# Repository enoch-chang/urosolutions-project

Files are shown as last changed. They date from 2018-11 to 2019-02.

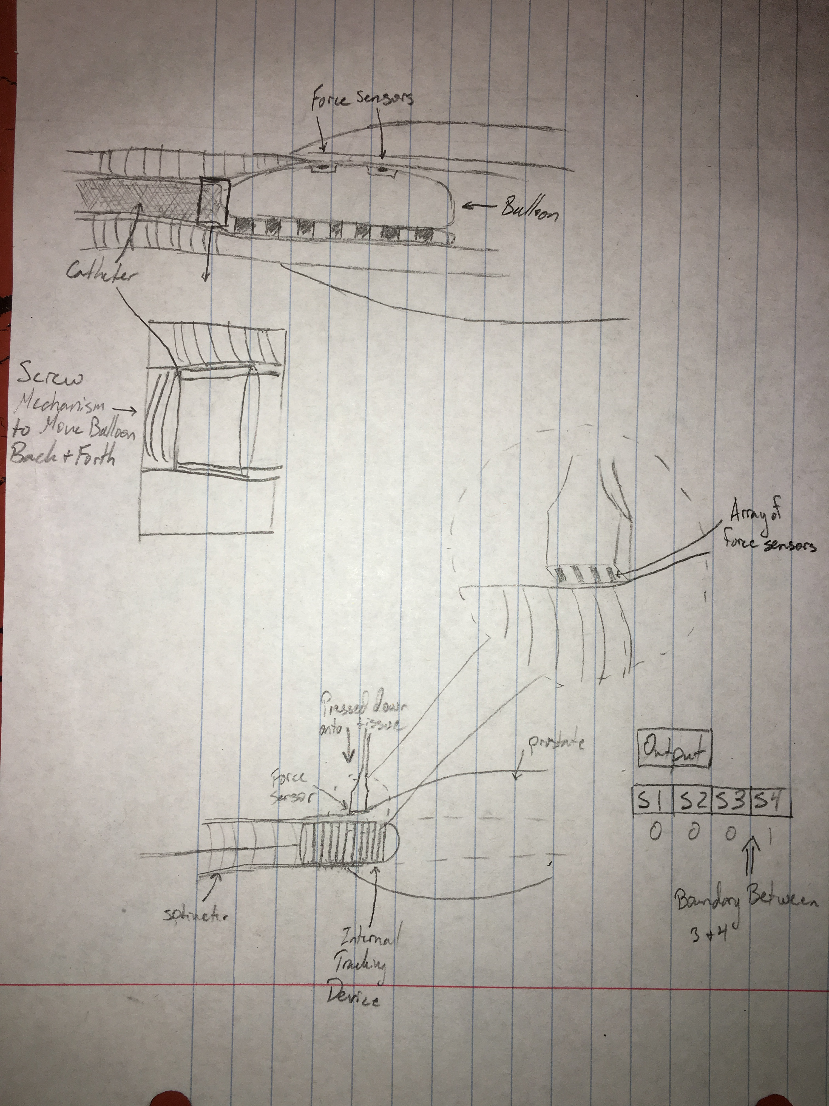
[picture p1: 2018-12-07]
Prototyping/Force_Sensing_Internal_External.JPG

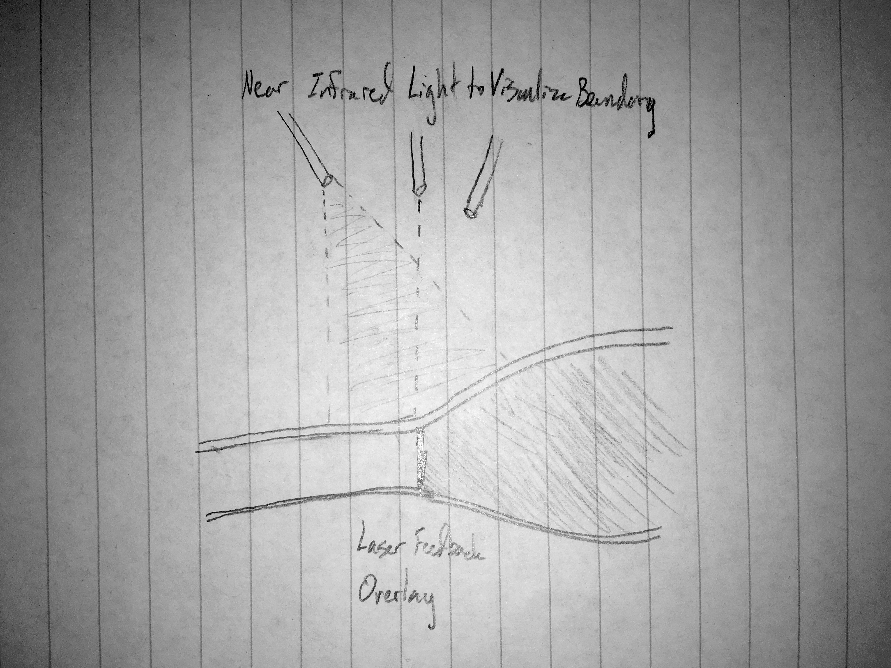
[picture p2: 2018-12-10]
Prototyping/Infrared_Sensing_Laser_Guidance.JPG

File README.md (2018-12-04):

# UroSolutions Project

This is the design repository for UroSolutions. Although the team collaborates on the documentation over Google Docs due to its real-time capabilities, all completed documentation is also uploaded onto the GitHub. 

The GitHub repository is organized into two main folders: Documentation and Prototyping. The Documentation contains files such as functional decomposition, the Design Foundation Document, background research and relevant Pugh matrices used to support design decisions. The Prototyping folder contains all material related to engineering aspects, from sketches, materials, CAD models, code and testing data for various iterations. Our Prototyping also includes relevant materials used in designing the testing models used to test our prototypes. Furthermore, the Milestones feature is used and updated regularly to facilitate achievement of objectives.

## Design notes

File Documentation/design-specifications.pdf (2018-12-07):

### Design Specifications

| | Spec #1 | Spec #2 | Spec #3 | Spec #4 | Spec #5
Priority | CUSTOMER NEEDS | Image Resolution | Measurement feedback time | Diameter of the device | Set-up and measurement time | Compatibility with surgical robotics
1 | The solution reduces recurrence of prostate cancer and severity of urinary incontinence | X
2 | The device clearly isolates and identifies the boundaries in imaging | X
3 | The solution does not present any additional sources of risk | | | X
4 | The solution must be simple to set-up and use | | X | | X | X
5 | The solution provides an indication for where to make surgical incisions | | X
6 | The device is compatible with laparoscopic surgical devices | | | | | X
| Competitive Value | - | - | 2.65 mm | - | -
| Marginal Value | - | - | 2.65 mm | - | -
| Ideal Value | 1 mm | 10 seconds | 2.6 mm | 10 minutes | Yes

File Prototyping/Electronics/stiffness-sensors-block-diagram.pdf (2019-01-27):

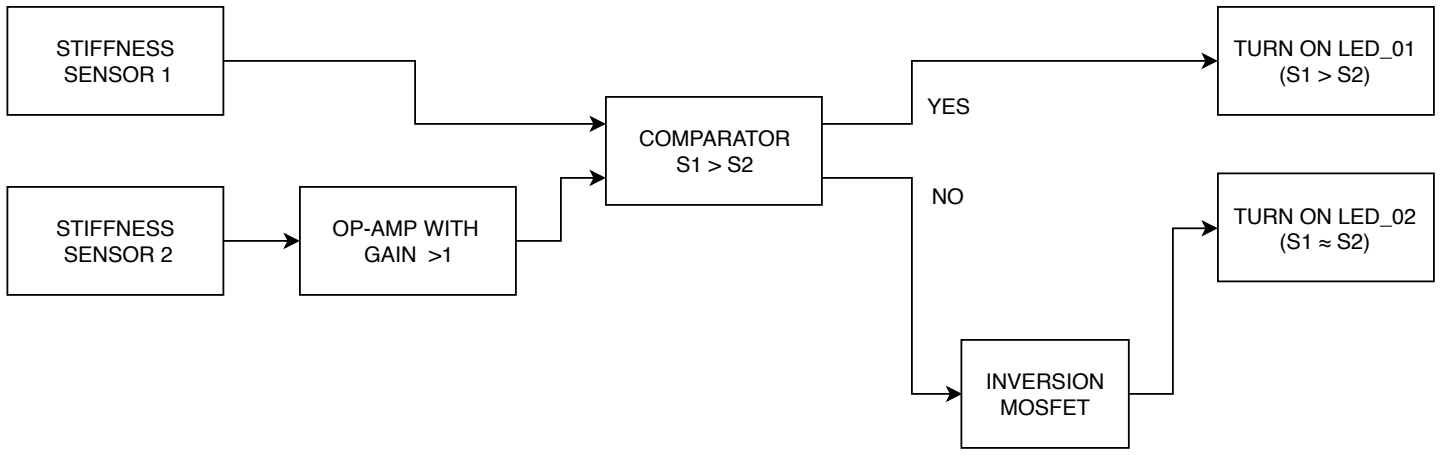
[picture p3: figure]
STIFFNESS SENSOR 1; STIFFNESS SENSOR 2; OP-AMP WITH GAIN >1; COMPARATOR S1 > S2; TURN ON LED_01 (S1 > S2); TURN ON LED_02 (S1 ≈ S2); YES; INVERSION MOSFET

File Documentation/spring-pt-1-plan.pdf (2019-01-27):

Spring Break Deliverable Plan: Functional Prototype

MVP

Our minimal viable product for the Spring break deadline will have the following characteristics and functionality:
- Detection of a stiffness difference between two media with stiffnesses representative of the sphincter and the prostate
- Balloon inflation mechanism is consistent and can attain stiffness readings
- Manual screw mechanism integrated with the balloon component and calibrated to attain the required imaging resolution
- Micro-controller software developed to be able to work through the full sequence of events (inflation, location detection/refinement, surgical tool positioning)
- Position of external sensor (for attachment onto the surgical tool) can be detected relative to the boundary that has been located

Tasks for after Spring Break (End of April Deadline)

Taking into account the initial vision and conception of the project scope, this is a list of features that will be implemented after Spring break for the final submission:
- Automation of the mechanical refinement process
- Improvement of the user input and display system to provide an intuitive user experience
- Adding additional sensors to increase ease of attaining an initial estimate of where the boundary is
- Optimize and reduce physical size of device (e.g. replacing Arduinos)

Schedule

Week | Stiffness | Boundary Location | Surgical Tool Detection | UI and General | Testing Model
2 | Sensor choice | Develop design and related specifications for the working mechanism | Test EM mechanism as a proof-of-concept | Draft and discuss IO requirements
3 | Sensor characterization on balloons | Mechanical and electrical design/ schematic | Configure two sensors along a line: electrical and software (Arduino) Test different EM sources | Mechanical design of what all the parts will look like together | Cardboard tube
4 | Sensor and balloon optimization | Prototype screw mechanism | Optimize the sensors and source with a chunk of meat Create indicator to show position of the tool relative to boundary | Create CAD drawing and begin mechanical prototyping | Gelatin model with one stiffness
5 | Continue sensor characterization; design of mechanical part | Prototype screw mechanism | Add third sensor for detection in 3D space; test out five configurations | | Gelatin model with two stiffness
6 | Construct balloon inflation mechanism | Circuit design and building | Test out five configurations (carried on from previous week) | Ensure mechanical design of all parts can be integrated
7 | | Circuit design and building
8 | Integration | | | | Test with device
9 | Demo

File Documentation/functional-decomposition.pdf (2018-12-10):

Functional Decomposition

Needs Statement: There is a need to clearly identify the boundary between the rhabdosphincter and the prostate in patients undergoing radical prostatectomies to reduce the severity of post-procedural urinary incontinence.

Solution: A device to clearly identify the boundary between the sphincter and the prostate to guide surgical incisions during radical prostatectomies using robotic surgery techniques

1. Measurement of mechanical stiffness of a medium
a. Conversion of force into an electrical signal
b. Sensor sensitivity required to detect differences in media with mechanical stiffnesses that correspond to the sphincter and prostate
2. Differentiation between the two anatomical structures through detecting differences in mechanical stiffness
a. Processing and analysis must translate raw data into measurements representing stiffness
b. Robust signal processing required to differentiate small local inhomogeneities and variations from change of medium
3. Identification and registration of the location of the boundary between the two structures
a. Choice of sensors and configuration must be able to achieve desired spatial resolution
b. Processing of raw data originating from multiple measurements taken by the probe along the surface
c. Analysis of raw sensor data must be able to provide the spatial location of the boundary
d. Provision of a notification for when a boundary has been definitively identified
4. Detection of the position of a surgical tool relative to the boundary
a. Processing must successfully triangulate the surgical tool’s relative position to the boundary
b. Real-time measurements and processing is necessary
c. Choice of sensors and configuration must be able to match the spatial resolution of the boundary
5. Indication of visual feedback to guide surgical incisions towards the boundary
a. Real-time processing of data relating to the relative position between the surgical tool and the boundary
b. Integration with robotic surgery unit
c. Easy for surgeon to view and understand

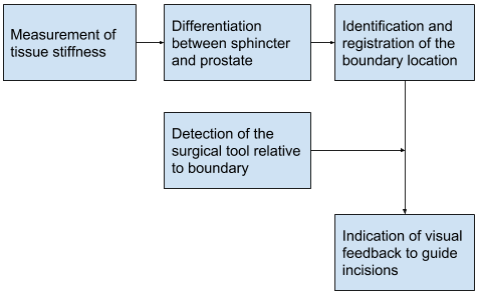
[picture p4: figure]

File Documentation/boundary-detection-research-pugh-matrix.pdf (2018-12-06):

Boundary Detection Pugh Matrix Research:
Objective: Evaluate 5 different boundary detection modalities
| Impedance | Infrared | Ultrasound elastography | Stiffness | Internal Pressure Sensing | Standard: Laparoscopic Palpation
Mm Resolution | 1 | 0 | 1 | 1 | 1 | 0
Compatible with Surgical Robotics | 1 | 1 | 0 | 1 | 1 | 0
Setup and Measurement Time | 1 | 1 | 1 | 0 | 1 | 0
Undistorted by surrounding tissues | 0 | 0 | 0 | 0 | 1 | 0
Total | 3 | 2 | 2 | 2 | 4 | 0

The first problem that needs to be overcome for our solution is to identify the location of the boundary between the two different tissues.
The rhabdosphincter structure is the tube shape of the urethra surrounded by two layers of muscle. The inner layer of longitudinal muscle is the lissosphincter and the outer layer of muscle wrapped in rings around the urethra is the rhabdosphincter.
The prostate is a significantly more complex organ. The transitional zone is immediately surrounding the prostatic urethra is a mix of glandular cells and smooth muscle cells. The outer layers of the prostate contain more of the glandular, prostatic fluid secreting cells.
Given the stark differences in cell types between the two structures there may be a vast number of macroscopically measurable differences between the two. We examined 5 different measurement modalities: Impedance measurement, infrared light detection, ultrasound elastography, stiffness measurement, and internal pressure sensing. Our results are summarized in the Pugh Matrix above and expanded upon in the research below.

Impedance Measurement
The basis of this technology is the detection of the resistance of the tissue in much the same way that a stud finder measures the differences in the wall to locate the boards in the wall. Edge detection- This is used to determine the first point at which a change occurs between two interfaces. In our case the best way to perform this would be to pass the device towards the boundary once and then from the other side once. This would allow you to place the center line twice and the difference between the two should be able to give you a small range within which to cut.

Alternative- Bipolar needle measurement
This method detects the impedance present between two electrodes positioned on a needle tip. This is different from monopolar measurement which uses a reference placed at the surface of the given tissue. Bipolar is generally considered to be more accurate.
Ideally you could stick the needle into the tissue in many different places and you could map out a rough boundary of where the cut location should be.
- Downside: It wouldn’t allow you to determine the precise location only a relatively rough guide based upon how close to the correct line you place the needle. It’s possible that you could extrapolate this more generally and place two electrodes a little bit further apart. This would allow you to measure differences over a range of tissue. But you would need to set these a fixed distance apart to be reasonable. At this point this basically becomes an edge detector similar to above.
This technology has the potential to have a very high resolution as the impedance measurements would likely be accomplished using a bipolar needle detection system. This technology could also leverage a combination of an internal and external probe in order to obtain the impedance difference over the larger bulk of tissue between the two instead of only at the tip of a needle. Depending upon the kind of impedance measurement this could be significantly distorted by other tissues that remain at the surface and are not cleared away adequately by the surgeon.

Infrared Light Detection
The basis of this technology is the application of near infrared light onto the surface of the urethra/sphincter and prostate. This light potentially allows the surgeon to observe the differences between the two different structures.
This technology borrows its general idea from a technology called Accuvein where NIR light is shined at the arm and the veins stand out in stark contrast. This is because of the differences in the absorbance of the NIR light between the deoxygenated hemoglobin in the blood and the rest of the surrounding tissue.
Another added benefit for this technology is the recent development of NIR dyes that are being applied to the treatment of prostate cancer. These dyes are intended to preferentially stain the cancerous tissue to guide surgery.
If this could be applied to the surgical field then it could potentially overcome the need for a separate boundary identification tool as it could remain in place during the actual cutting. This technology however also has a large number of unknowns. It would be difficult to test outside of the body because it is difficult to determine exactly what part or property of each tissue causes it to absorb the light preferentially. As a result it is difficult to say whether there is a significant enough difference between the tissues to actually identify the boundary. Finally, this technology would also be very prone to noise from the surrounding tissues like fat or fascia which are cleared away during the surgery.
Ultrasound Elastography
The basis of this technology is the excitation of a tissue with acoustic waves and the detection of the reflected acoustic waves. The idea is that tissues with different stiffnesses will reflect the acoustic waves differently.

- A high frequency probe is used to generate an acoustic radiation force within the tissue, causing local tissue displacements. The probe can switch to an imaging mode to such that these displacements are tracked as they correspond to the dissipation of acoustic energy depending on the mechanical properties.
- In ARFI, the push region is tracked the tissue reverts to its pre-pushed state
- In shear wave elastography, shear waves are generated by the acoustic radiation force, propagating outwards from the focal point. The higher the velocity, the greater the shear modulus
This measurement method is able to achieve sub millimeter level resolution and also has a significant body of research backing it up. However, the probe is potentially prohibitively expensive and would need to be significantly modified in order to fit into the laparoscopic surgical method. Also, given that this is a technology that is somewhat beyond our skillset it would be difficult to prototype.

Stiffness Measurement
The basis of this technology is that the relatively elastic urethra/sphincter structure will feel significantly different than the much firmer prostate gland.
- Biological tissues such as the prostate do not behave in a purely linear elastic manner instead they behave in a viscoelastic manner – related to the proportions of viscous and elastic tissue that make up the specific tissue.
- Current prostate elastic theory states that the epithelial tissue predominantly composed of acini (water filled glands) act in a viscous manner whereas the stromal (predominantly elastic smooth muscle) component acts in an elastic manner.
- Applying the current viscoelastic model to other tissues we would expect the bladder and rhabdosphincter (predominantly composed of muscle) to behave more elastically (have lower amplitude ratio (AR), mean ratio (MR)) in comparison to prostatic tissue.
This measurement modality has the inherent appeal of an obvious macroscopic difference between the tissues. There are technologies that exist in this area already although as of yet they have not been able to achieve the resolution that is required for our application. During the surgery the surgeon needs to resect a significant amount of fat and fascia from around the prostate and the urethra and this is an other significant source of potential error in the stiffness measurement.
Internal Pressure Sensing
This method varies widely from all of the previous methods because it focuses around the detection of the boundary from the inside of the urethra rather than outside within the surgical field. It would involve the application of pressure or some kind of force outwards from a probe in the urethra to evaluate the stiffness differences between the two structures.
One benefit of this system is that it would leverage an already significant body of work that has gone into the development of balloon based catheters. These catheters are used in a variety of procedures from electrical stimulation and ablation in the heart to cystography and injection therapy in urologic applications. The idea behind this device would be to place force sensors on the balloon of the catheter which would be selectively inflated and deflated with a controlled volume in order to examine the stiffness of the surrounding tissues. With multiple force sensors we would be able to identify the precise location to cut down to the desired millimeter resolution.

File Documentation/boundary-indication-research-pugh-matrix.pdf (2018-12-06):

Boundary Indication Pugh Matrix Research:
Objective: Evaluate 5 different boundary indication modalities
| Laser Feedback | Audio Feedbac k | Image Overlay | Visual Proximity Meter | Ink | Standard: Do Nothing
Able to integrate with the cutting tool | 1 | 1 | 1 | 1 | 0 | 0
Feasible to solve | -1 | 1 | -1 | 1 | 1 | 0
Able to stay localized on the boundary | 0 | 1 | 1 | 1 | 0 | 0
Unintrusive to use | 1 | -1 | 1 | 1 | 1 | 0
Total | 1 | 2 | 2 | 4 | 2 | 0

The second barrier that needs to be overcome by our solution is making sure that the surgeon is able to keep track of the boundary. It’s completely unhelpful to find the boundary if they’re unable to keep track of it in order to make the cut at the right location. So there is need for a way to keep track of the boundary in order to guide the tool to the proper location. We examined 5 different feedback modalities: Laser Feedback, Audio Feedback, Image Overlay, Visual Proximity Meter, and Ink. Our results are summarized in the Pugh Matrix above and expanded upon in the research below.

Laser Feedback:
The basic idea behind this solution is to place a laser line on the surface of the tissue. This laser would be targeted at the specific location of the boundary that would be detected using one of the technologies discussed in the detection Pugh matrix. This would have the benefit of having high resolution.
The problems with this technology are multifold. The first is that there would need to be a separate laser tool that would need to be inserted into the body. Then there would need to be an advanced tracking algorithm to determine exactly where the laser is coming from and the exact angle that it needs to be at to place the laser at the boundary.
There is potential to get a little more creative with the laser placement by integrating it either with the cutting tool or by placing some kind of marker on the surface of the tissue that generates the laser at the proper location based upon the detection mechanism.

Audio Feedback:
The basic idea behind this solution would be to integrate an audible tone that changed based upon the distance away from the boundary. This tool would require integration with some form of tracking. A sensor would be placed onto the cutting tool and this would be tracked by the detection tool which holds the place of the boundary relative to reference points. Ultimately one drawback of this technology would be that it might be somewhat annoying over the course of a very long surgery no matter how much work was placed into making the tone not too grating.

Image Overlay:
The basic idea behind this solution would be to use image processing to track the precise location of the boundary on the visual field of the laparoscopic camera and to display a line that the surgeon could cut along to cut precisely on the boundary. The one immediate barrier to this solution is the vast amount of image processing that would need to be performed to ensure that the boundary is as precise as possible. The complexity would only increase as the camera moves or the tissue is shifted during the course of the surgery.
Visual Proximity Meter:
The basic idea behind this solution would be to integrate a visual meter that would allow the surgeon to visualize how far the cutting tool is away from the boundary. This method is similar in many ways to the Audio Feedback solution discussed above but instead of an audible tone the feedback is given in the form of a visual dial. This dial would track the lateral movement across the tissue instead of 3 dimensions. This dial could be overlaid onto the surgical view and would seamlessly allow the physician to monitor their distance from the boundary in real time.

Ink:
The basic idea behind this solution would be to mark the boundary with some form of ink during the boundary detection process. This could be integrated into a separate surgical tool or could be integrated as the boundary is identified. One problem with this method is that it would suffer from limited resolution and would also potentially have difficulties in maintaining the precise location of the boundary over time. The ink would need to be resistant to the blood that is everywhere during the surgery. It would also be subject to noise from the different tissue types that are present at the surface of the prostate-sphincter boundary.

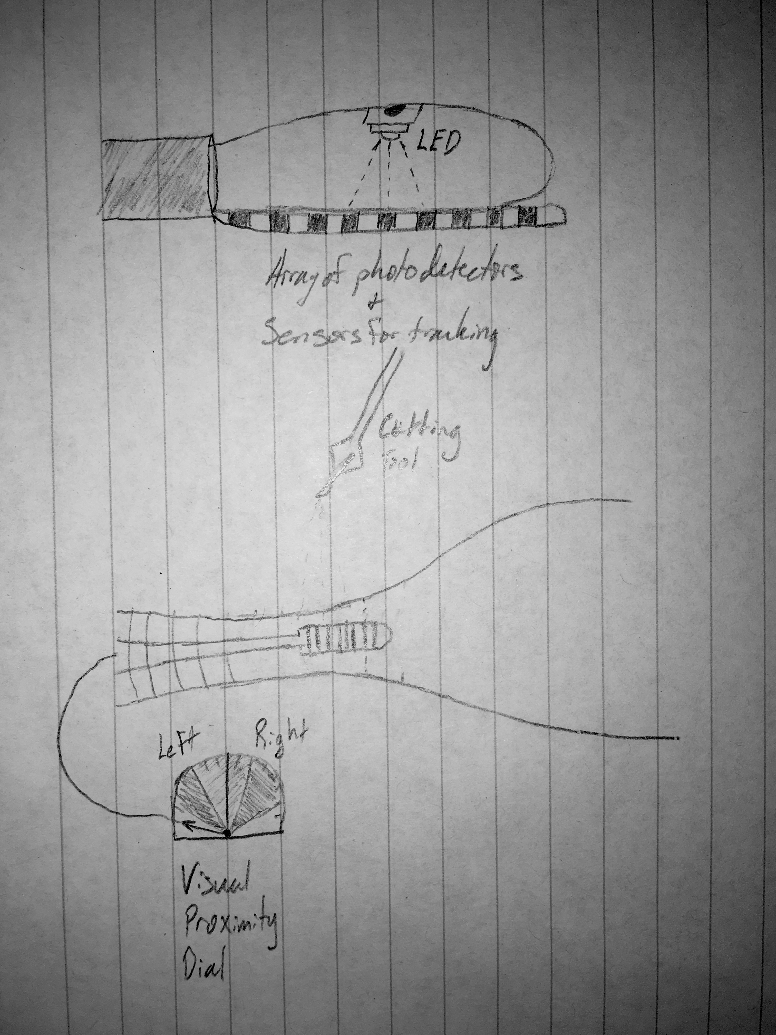
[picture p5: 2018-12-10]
Prototyping/Photodetector_Sensor_Visual_Proximity_Dial.JPG

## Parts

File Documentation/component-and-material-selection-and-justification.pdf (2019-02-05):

Component and Material Selection and Justification

I. Stiffness sensor

Required specifications and characteristics:
- Small sensing area for spatial resolution
- 5 mm
- Sensing area can be pushed onto soft surfaces for effective contact
- Mountable onto balloon or expanding surface (flexible)
- Sensitivity is sufficient in detecting differences between tissue (i.e. at least 20 kPa resolution)

II. Balloon material

Required specifications and characteristics:
- Constant expansion longitudinally (along the urethra)
- Durable material to reduce risk of bursting in vivo
- Size (for spring break functional prototype, final one will be much smaller)
| Sensitivity | Flexibility | Small sensing area | Effective contact on soft surfaces
MPL115A2 (Barometer) | X (.15kPa) | X | √ | X
MPL3115A2 | √ (1.5 Pa) | X | √ | X
Interlink 402 (FSR) | √ (0.1 N) | √ | X | √
Interlink 400 (FSR) | √ (0.2 N) | √ | √ | √

Interlink 408 (FSR)

| Expands beyond diameter of 4 cm | Expands longitudinally | Durability
Standard Party Balloon | X | X | X

III. Surgical tool tracking sensing mechanism

Required specifications and characteristics:
- Sensing can be performed through a thickness of tissue
- Sensor should yield analog reading
- Signal not distorted (e.g. by dispersion) when passing through the tissue
- Sensitivity should be able to achieve the spatial resolution
- Mountable onto balloon or expanding surface; receiver must be mountable to surgical tool
Condom | √ | √ | √
Party Balloon (for balloon animals) | √ | √ | ~
Medical Grade balloon | | √ | √
| Not attenuated or dispersed by tissue | Analog reading | Sensitivity | Resistant to Noise
Wire Coil (EM) | X | √ | X | XX
AX01838HS (IR sensor) | / | X | / | X
US5881LUA (Hall effect sensor) | √ | √ | √ | √

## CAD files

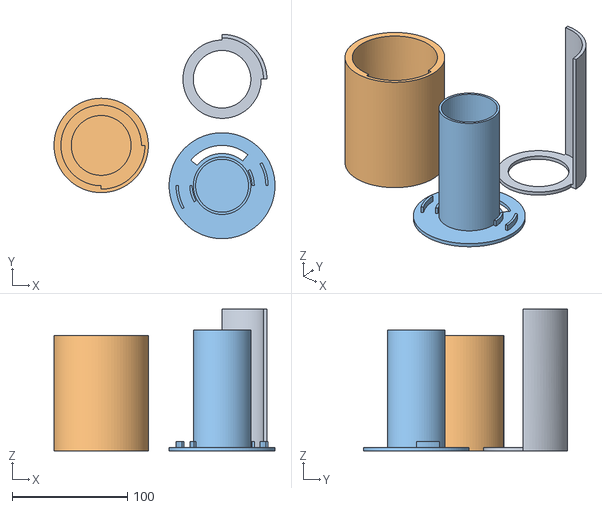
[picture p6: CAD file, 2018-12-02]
Prototyping/Mechanical/Gelatin_Mold_Design/gelatin-mould-3-pcs.stl
192.0 x 177.5 x 123.0
"gelatin-mould-3-pcs" x 3

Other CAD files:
Prototyping/Mechanical/Gelatin_Mold_Design/Gelatin_Mold_Outer v4.f3d
Prototyping/Mechanical/Gelatin_Mold_Design/Gelatin_Mold_Remover v1.f3d
Prototyping/Mechanical/Gelatin_Mold_Design/Gelatin_Mold_Remover v2.f3d
Prototyping/Mechanical/Gelatin_Mold_Design/Gelatin_Mold_Remover v4.f3d
Prototyping/Mechanical/Gelatin_Mold_Design/Gelatin_Mold_Top v2.f3d
Prototyping/Mechanical/Gelatin_Mold_Design/Gelatin_Mold_Top v4.f3d
Prototyping/Mechanical/Gelatin_Mold_Design/Gelatin_Mold_Top v5.f3d
Prototyping/Mechanical/Prostate_Boundary_Detection_External v2.f3d
Prototyping/Mechanical/Prostate_Boundary_Detection_Internal v3.f3d

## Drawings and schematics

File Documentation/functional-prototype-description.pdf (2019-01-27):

Functional Prototype Description

Sequence of Events

1. Insertion of catheter into the urethra
2. Inflate balloon until certain volume is reached using a syringe
3. Manual adjustment to get estimated region of boundary (i.e. boundary is located between the two sensors on the balloon) where the two sensors give different readings
4. Mechanical refinement of the position such that active sensor (one of the two stiffness sensors selected) is aligned, as closely as possible, with the location of the boundary
5. Detection of the surgical tool relative to the boundary location detected

Decomposition

The device can be split into three main parts:
A. Balloon inflation
- Input: Syringe
- Output: /
- Process: /
B. Stiffness measurement and boundary detection
- Input: Button to measure stiffness from two sensors, stiffness sensors (2)
- Output: light to indicate that boundary is between the two sensors, light to indicate that two sensors are in the same tissue region
- Process: Comparison of stiffness signals from each sensor to toggle lights
- Implemented using analog circuit components
C. Surgical tool positioning
- Input: EM sensors (3), switch to activate EM field on surgical tool, switch to turn on EM sensors on catheter
- Output: Display or lights to show proximity or relative position between the surgical tool and the boundary
- Process: Detection of position of the EM source and calculation of proximity to toggle display/indication
- Implemented using an Arduino micro-controller

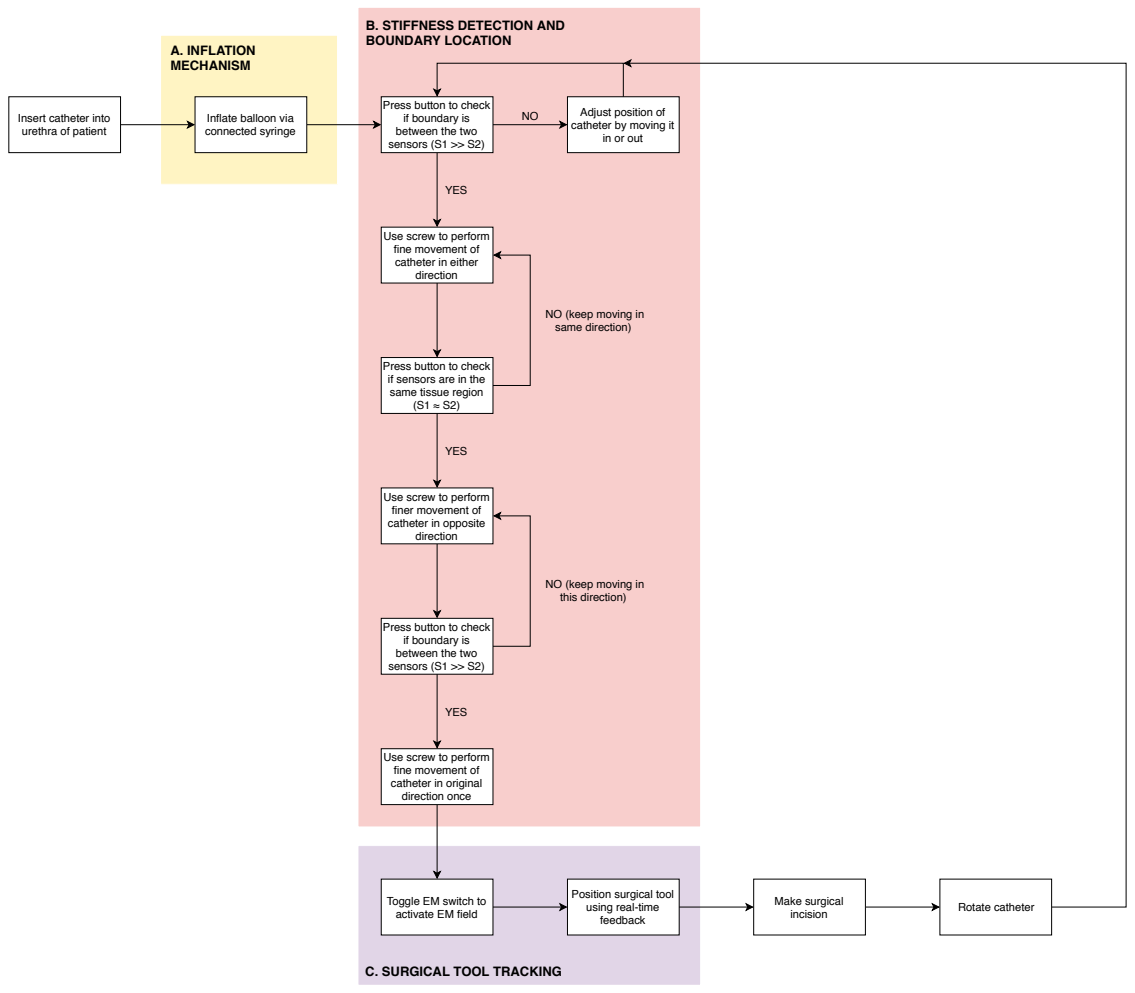
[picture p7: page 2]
YES; Make surgical; incision; Rotate catheter; A. INFLATION MECHANISM

B. STIFFNESS DETECTION AND
BOUNDARY LOCATION

Press button to check
if boundary is
between the two
sensors (S1 >> S2)

Adjust position of
catheter by moving it
in or out

Insert catheter into
urethra of patient

Inflate balloon via
connected syringe

Use screw to perform
fine movement of
catheter in either
direction

NO (keep moving in
same direction)

if sensors are in the
same tissue region

finer movement of
catheter in opposite

this direction)

catheter in original
direction once

Toggle EM switch to
activate EM field

Position surgical tool
using real-time
feedback

C. SURGICAL TOOL TRACKING

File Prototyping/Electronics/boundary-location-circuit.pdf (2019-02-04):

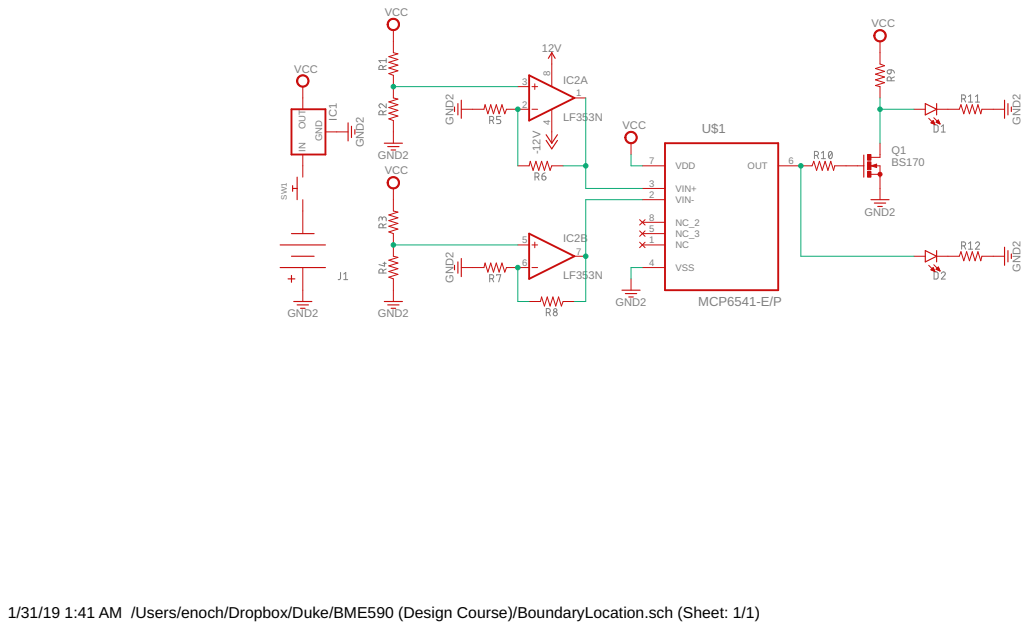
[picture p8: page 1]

1/31/19 1:41 AM /Users/enoch/Dropbox/Duke/BME590 (Design Course)/BoundaryLocation.sch (Sheet: 1/1)

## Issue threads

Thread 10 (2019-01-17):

Develop the balloon probe for the stiffness sensing

mgood13, 2019-01-17:
1. Convert the single sensor modality that we have into the balloon model that will work with our testing rig
2. Test a volume of material to fill the balloon with

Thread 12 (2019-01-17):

Create a 2D prototype of the location tracking

mgood13, 2019-01-17:
1. Build the Arduino set up of the location tracker
2. Add a second sensor and develop the algorithm to create a 2D map with the two sensors

mgood13, 2019-01-22:
- [x] Research competitive devices

- [x] Create Arduino Sketch for distance tracking

- [x] Create 2D board for distance tracking calibration

- [x] Create circuit design for multi-dimensional tracking

- [ ] Derive equation for 2D position

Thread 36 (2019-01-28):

Arduino frequency calculation

mgood13, 2019-01-28:
Make Arduino sketch for detaining frequency from input sensor

mgood13, 2019-01-28:
- [ ] Make Arduino Sketch

- [ ] Make modified circuit

- [ ] Make Eagle Circuit

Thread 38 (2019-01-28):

Develop circuit to amplify input signal

mgood13, 2019-01-28:
Signal works only at short distances, need more op-amps

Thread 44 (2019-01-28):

Breadboard implementation of comparator circuit with placeholders for the stiffness sensors

enoch-chang, 2019-01-28:

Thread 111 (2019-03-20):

Redesign CAD model

mgood13, 2019-03-20:

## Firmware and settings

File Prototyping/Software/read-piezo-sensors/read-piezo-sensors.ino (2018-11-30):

#define PIEZOELECTRIC_SENSOR_1 A0
#define PIEZOELECTRIC_SENSOR_2 A1
#define BIT_DEPTH 1023
#define MAX_VOLTAGE 5

float sensor_1 = 0;
float sensor_2 = 0;

void setup() {
  // put your setup code here, to run once:

  Serial.begin(9600);

  pinMode(PIEZOELECTRIC_SENSOR_1, INPUT);
  pinMode(PIEZOELECTRIC_SENSOR_2, INPUT);

}

void loop() {
  // put your main code here, to run repeatedly:

    sensor_1 = read_sensor(PIEZOELECTRIC_SENSOR_1);
    sensor_2 = read_sensor(PIEZOELECTRIC_SENSOR_2);
    Serial.print("Sensor 1: ");
    Serial.print(sensor_1);
    Serial.print("\n");

    Serial.print("Sensor 2: ");
    Serial.print(sensor_2);
    Serial.print("\n");
}

float read_sensor(int pin){
    unsigned int sensorValue = analogRead(pin); //read the A0 pin value
    float voltage = sensorValue * (MAX_VOLTAGE / BIT_DEPTH); //convert the value to a true voltage. 
    return voltage;
  }

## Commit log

2018-11-30 Added Arduino code for sensor detection
2018-11-30 Added in Fusion360 Models
    [Prostate_Boundary_Detection_External v2.f3d, Prostate_Boundary_Detection_Internal v3.f3d]
2018-12-01 Adding first gelatin mold designs
    [Gelatin_Mold_Outer v4.f3d, Gelatin_Mold_Remover v1.f3d, Gelatin_Mold_Top v2.f3d]
2018-12-01 Adding the ring shaped remover
    [Gelatin_Mold_Remover v2.f3d]
2018-12-02 Added .stl and .gcode files for the moulds combined into one file -- ready for print
    [gelatin-mould-3-pcs.stl]
2018-12-03 Updating Parts so that they fit together
    [Gelatin_Mold_Remover v4.f3d, Gelatin_Mold_Top v4.f3d]
2018-12-06 Adding the Bottom of the middle piece
    [Gelatin_Mold_Top v5.f3d]
2018-12-10 Updated functional decomposition and sketches; Added pitch deck
2019-01-27 Added plan for spring semester (first half) and breakdown of how the device works
2019-01-27 Added circuit block diagram
2019-02-04 Added circuit diagram for boundary location and relevant datasheets
